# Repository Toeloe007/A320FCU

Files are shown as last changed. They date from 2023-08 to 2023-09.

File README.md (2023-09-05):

# A320FCU
Homebuilt FCU for the Fenix A320 (MSFS2020) 50-60€

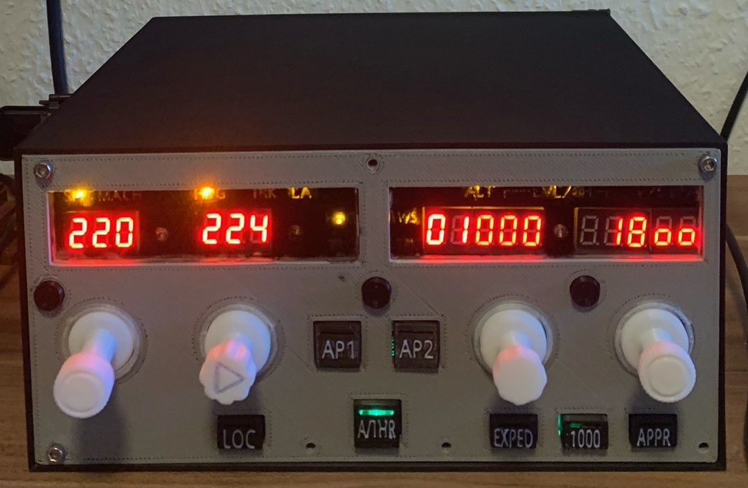
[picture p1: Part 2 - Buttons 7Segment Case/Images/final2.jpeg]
Preview


Since English is not my native language, I apologize in advance for any spelling and grammatical errors.

I would like to share my self-built FCU with you. It is relatively similar to the real FCU and includes all functions. It is also very interesting in price, you just have to invest time in the project.

The project is divided into 2 parts. 
- [Part 1 - knobs with push pull function and backlighting](./Part%201%20-%20Rotary%20Buttons/)
    - Inspired by [Mantoga](https://www.printables.com/de/model/504680-airbus-a320-fcu-push-pull-mechanism), who provided the print files of the push-pull mechanism.
- [Part 2 - The 7 segment displays, all LEDS and the box](./Part%202%20-%20Buttons%207Segment%20Case/)

## Basic Requirements
- 3D Printer with Slicer Software
    - Color Transparent
    - Color White
    - Color Grey
    - Color black
- Some knowledge about electricity
- Arduino Mega
- [Project Fenix Quartz](https://github.com/Fragtality/FenixQuartz)
- Mobiflight

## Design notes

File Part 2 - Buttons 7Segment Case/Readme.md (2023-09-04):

# Part 2 - 7Segment Displays, Buttons and LEDs
This part covers the assembly of the 7Segment Display, the Buttons and the LED

## Parts needed
- 16x [LED yellow](https://de.aliexpress.com/item/32757762886.html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)
- 7x [LED green](https://de.aliexpress.com/item/32757762886.html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)
- 16 [8x8 Non-Self-Locking Button](https://de.aliexpress.com/item/4001159367703.html?spm=a2g0o.cart.0.0.5fbb4ae4lgbDyt&mp=1&gatewayAdapt=glo2deu)
- 2x [10uF elektrolyt capacitor](https://de.aliexpress.com/item/32951751425.html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)
- 2x [100nF cermaic capacitor](https://de.aliexpress.com/item/1005001356274653.html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)
- 4x [7 segment 3 Bit 0.36 common cathode](https://de.aliexpress.com/item/1005005667523190.html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)
- 2x [7 segment 2 Bit 0.36 common cathode](https://de.aliexpress.com/item/1005005667523190.html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)
- 2x [Max 7219](https://de.aliexpress.com/item/1005004266394173.html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)
- 2x [DIP24](https://de.aliexpress.com/item/1005005432295225.html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)
- Some [PCD Boards](https://de.aliexpress.com/item/1005004818919331.html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)

## Preview
[Finished assembly](./Images/)

## Electronic Shematic
TODO

# 3D Printing
## Front
Print the front with 50% infill

## Buttons
All Buttons can be printed with 10% infill.

## Electrical assembly
Take a look to the [Datasheets](./Datasheets/) and doublecheck if you have the same 7Segment Display as the datasheet is. Otherwise get the correct datasheet. 

Wiring is easy but takes a lot of time.
One Max7219 can handle 8Digits. You have 16 Digits, so you need 2 Max7219. 

I have connected Speed, Heading and the first 2 digits of the Alt display to the first 7219. The remaining 3 digits of the Alt display and all digits of the VS display are connected to the second 7219.

The segments of the displays that belong on a Max7219 must all be connected together. The segment connections are each connected individually to the 7219. See the data sheets. Additionally the 7219 needs 5V at the V+ input. In parallel to the power supply 2 capacitors must be connected in parallel. A 10uF electrolytic capacitor and a 100nF cermaic capacitor. The other side of the capacitor belongs to GND. Furthermore the 7219 needs at the ISET input a 41k Ohm resistor with a 5V power supply.

Wiring the rest is pretty simple. Each button needs GND and is connected to the Arduino at the switch wire. Each LED needs a series resistor. I recommend to try each light color with different resistors to get the desired brightness. Please note that 20mA per output should not be exceeded.

Pin Arduino | Description 
38	        | AP1 Btn  
39	        | Ap1 LED  
40	        | AP2 Btn  
41	        | AP2 LED  
42	        | LOC BTN  
43	        | LOC LED  
44	        | ATHR BTN  
45	        | ATHR LED  
46	        | EXPED BTN  
47	        | EXPED LED  
48	        | 1000 Btn  
49	        | 1000 LED  
50	        | APP BTN  
51	        | APP LED  
52	        | SPD Mach Btn  
53	        | HDG TRK Btn  
2	        | MET ALT Btn  
3	        | SPD LED  
4	        | MACH LED  
5	        | HDG LED  
6	        | TRK LED  
7	        | VS LED  
8	        | FPA LED  
9	        | SPD Managed LED  
10	        | HDG Managed LED  
11	        | Alt Managed LED  

## Assembly
In the 3D files directory there are different Pins to glue the components together.

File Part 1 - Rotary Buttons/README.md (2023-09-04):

# Part 1 - Rotary Buttons with Push Pull Function
This part covers the assembly of the Rotary Button with Push Pull function.

## Parts needed
- 16 [8x8 Non-Self-Locking Button with Black Cap](https://de.aliexpress.com/item/4001159367703.html?spm=a2g0o.cart.0.0.5fbb4ae4lgbDyt&mp=1&gatewayAdapt=glo2deu)
- Rubber mat 2mm
- 6mm Brass Shaft approx 4x125mm
- 4x 20x2mm Steel Pin
- 4x [Rotary Encoder](https://de.aliexpress.com/item/1005002358274622.html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)
- 12x [Warm White LED 3x3mm Flat Top](https://de.aliexpress.com/item/32757762886.html?spm=a2g0o.cart.0.0.230b4ae42b9wfW&mp=1&gatewayAdapt=glo2deu)
- Wiring Material
- Rapid glue
- [Power Module](https://de.aliexpress.com/item/4000532944497.html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) for Backlight and 7 Segment display 5V-5W
- [Power Plug with Switch](https://de.aliexpress.com/item/1005002288319626.html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) for Power Module
- 12x 220 Ohm resistor for LED lighting

## Preview
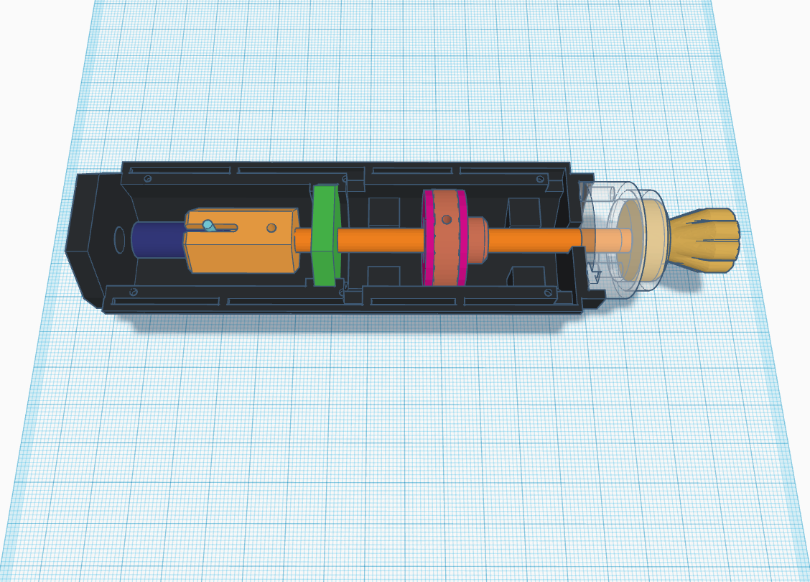
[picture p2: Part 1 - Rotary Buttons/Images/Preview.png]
Preview

[Finished assembly](./Images/)

## Electronic Shematic
[Backlight Shematic](./Electronics/Backlight_shematic.png)  
[Example Shematic](./Electronics/Example-shematic.png)

## 3D Printing
Print everything with 10% infill except the transparent part. Print the transparent part with 0% infill.

## Assembly
It is recommended to assemble 1 knob first as a test. And then learn from your mistakes.
1. print all 3D parts
2. glue the two parts of the button together
3. take a 6mm drill and drill the Light Pipe Support and the Centre Support (photo green) a little bit bigger. The brass rod must go through without friction. 
4. Glue the transparent part on the housing. ATTENTION: Put a LED in the lower cutout before, otherwise you won't be able to reach it.
5. install the encoder
6. glue the steel pin into the encoder pin. (photo cyan and dark blue)
7. glue the punched out rubber mat (photo pink) on the push pull disc.
8. put everything together carefully and check if the brass rod has the right length. If not, shorten the rod.
9. Remove everything except the encoder pin. 
10. put super glue in the hole of the encoder slide and put the encoder slide on the encoder pin
11. insert Centre Support
12. insert brass rod and don't forget the push pull disc!!!
13. glue brass rod and Encoder Slide together
14. wire the push button and glue it. Make sure that the Push Pull Disc is still free to move after gluing in the push buttons. Approx. 1mm distance
15. Push the brass rod almost all the way to the back. Approx. 1mm distance
16. push the push pull disc backwards. Operate the push mechanism and glue the push pull disc in the same way. 
17. After the glue has dried, operate the push mechanism again and glue the knob flush with the light pipe in this state.

If everything is done correctly, you can turn the knob and feel the steps of the encoder. In addition, you can press the push-pull mechanism and it will return to its original position by itself.

## Electrical assembly
All parts are connected to GND. This means that the middle pin of the encoder has to be connected to GND and the pushbuttons also all need GND. The push buttons have to be connected in parallel. So the push buttons for push together and the push buttons for pull together.

Pin Arduino | Description  
22	        | Altitude left  
23	        | Altitude right  
24	        | Push Altitude  
25	        | Pull Altitude  
26	        | Speed left  
27	        | Speed right  
28	        | Push Speed  
29	        | Pull Speed  
30	        | VS left  
31	        | VS right  
32	        | Push VS  
33	        | Pull VS  
34	        | HDG left  
35	        | HDG right  
36	        | Push HDG  
37	        | Pull HDG  

### Backlight
Since I don't want to load my USB ports unnecessarily, I decided to power the backlight via an external power supply.
The GND pin of the power module has to be connected to the GND pin of the Arduino.

The cathodes (-) of the LEDs can all be connected together and then connected to GND.
Each LED needs a 220 Ohm resistor at the anode (+). Connect all resistors together on one side and put them on the 5V of the power module.

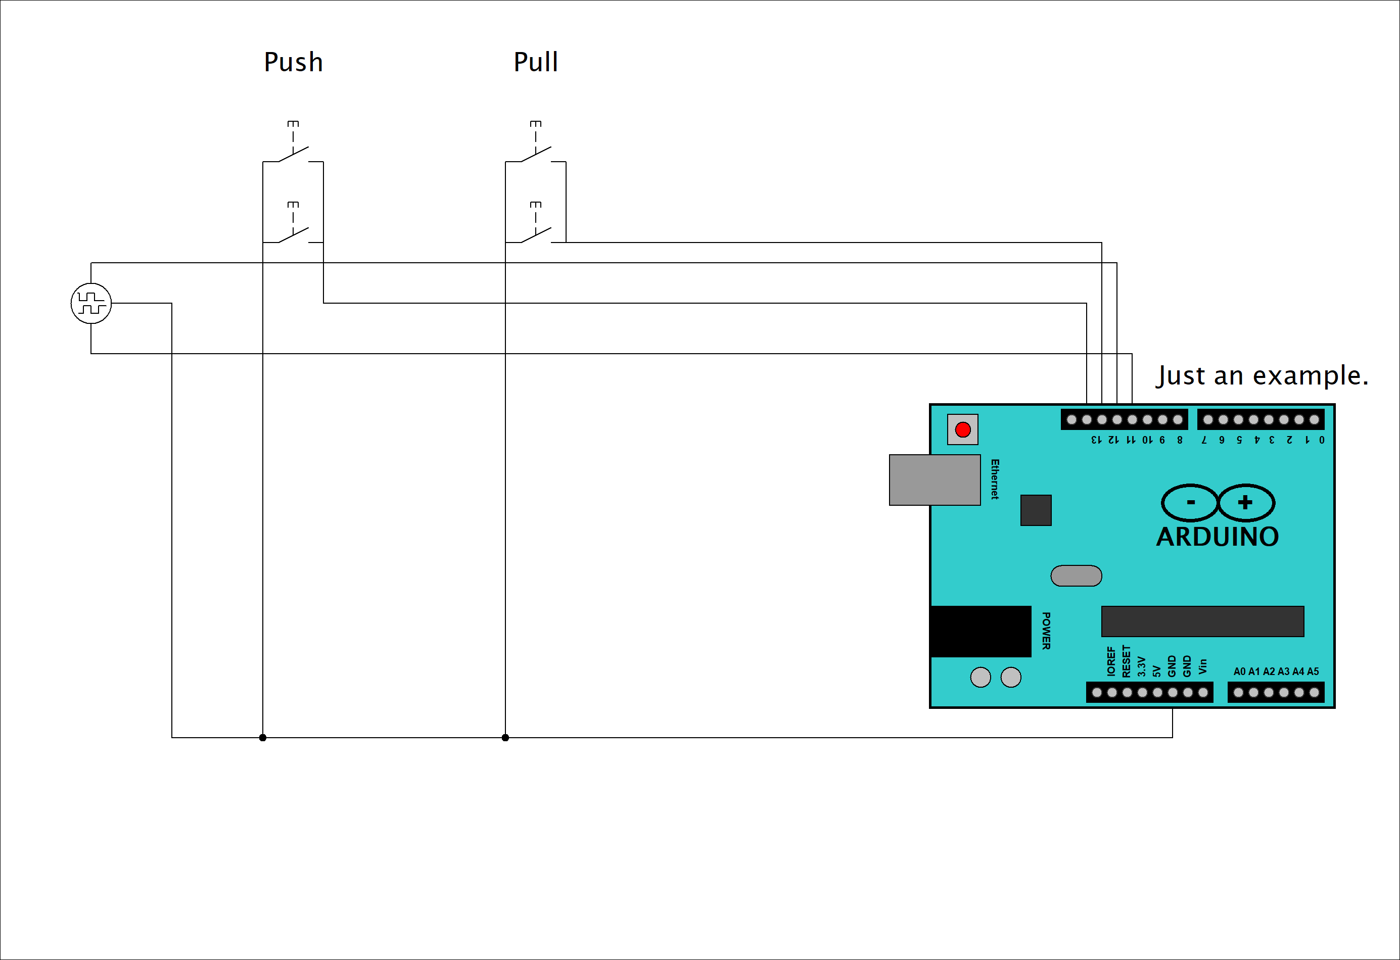
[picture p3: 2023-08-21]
Part 1 - Rotary Buttons/Electronics/Example-shematic.png

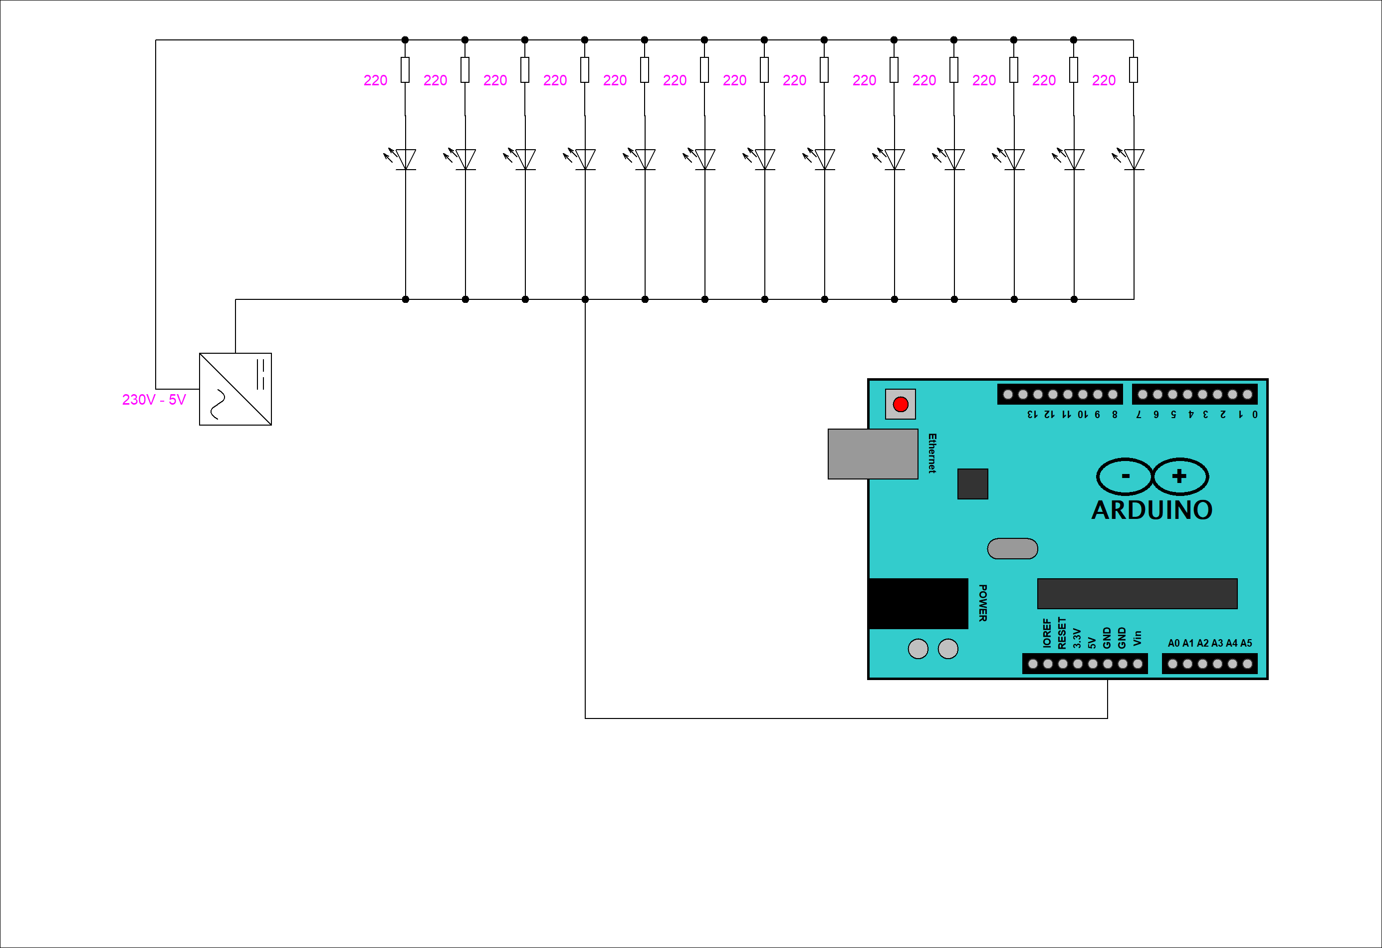
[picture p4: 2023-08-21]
Part 1 - Rotary Buttons/Electronics/Backlight_shematic.png

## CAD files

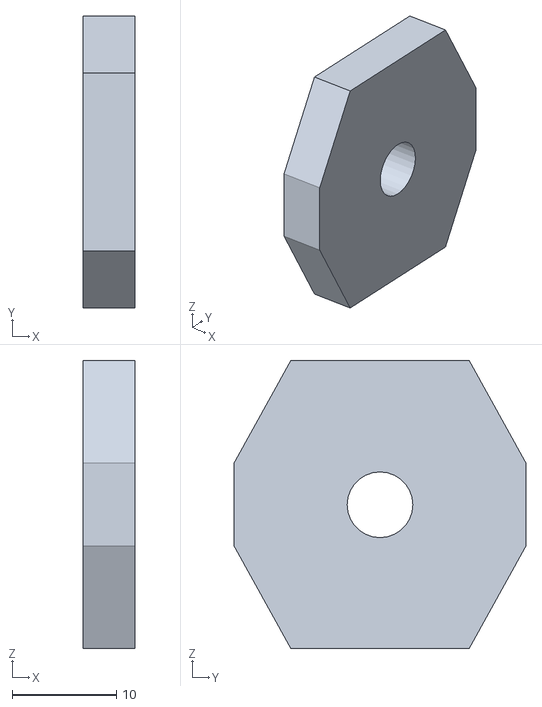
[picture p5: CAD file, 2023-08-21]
Part 1 - Rotary Buttons/3D Files/4x black Centre Support.stl
5.00 x 28.0 x 27.7

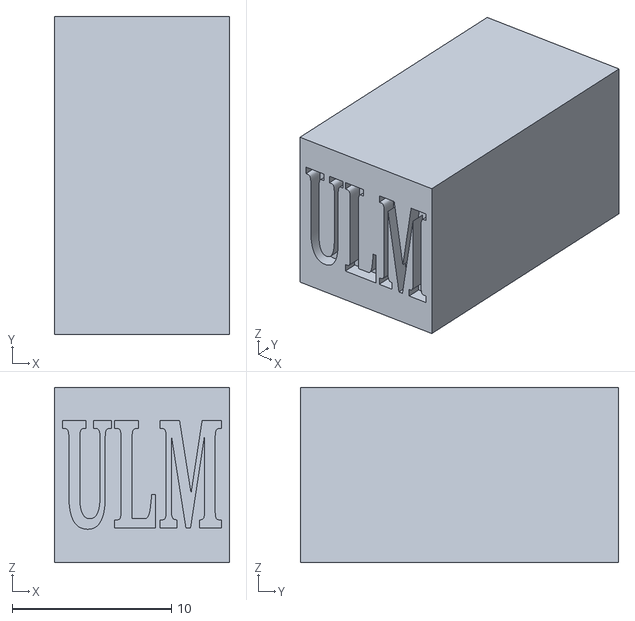
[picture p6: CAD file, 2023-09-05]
Part 2 - Buttons 7Segment Case/3D Files/Box_ULM.stl
11.0 x 20.0 x 11.0

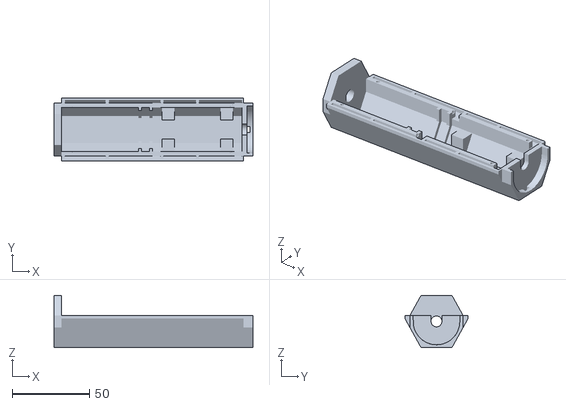
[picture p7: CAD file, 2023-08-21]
Part 1 - Rotary Buttons/3D Files/4x black Chassis.stl
129.0 x 41.0 x 34.0

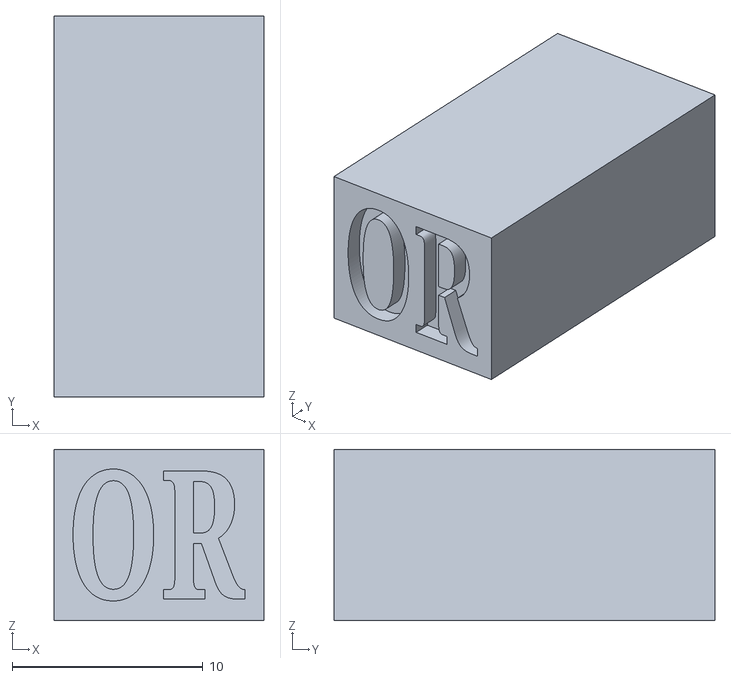
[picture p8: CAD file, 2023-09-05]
Part 2 - Buttons 7Segment Case/3D Files/Box_OR.stl
11.0 x 20.0 x 9.00

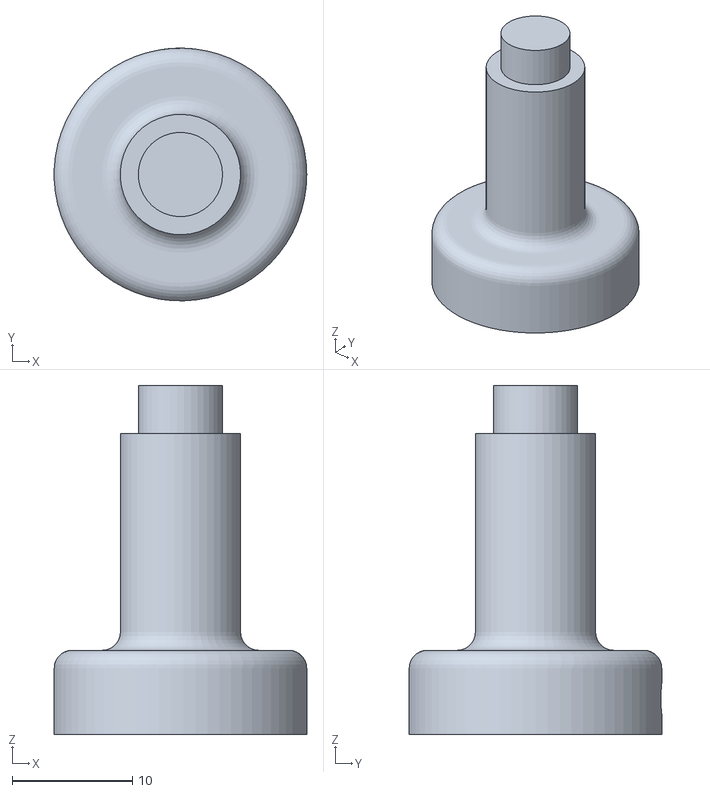
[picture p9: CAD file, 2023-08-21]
Part 1 - Rotary Buttons/3D Files/1x white Speed Knob Base.stl
21.0 x 21.0 x 29.0

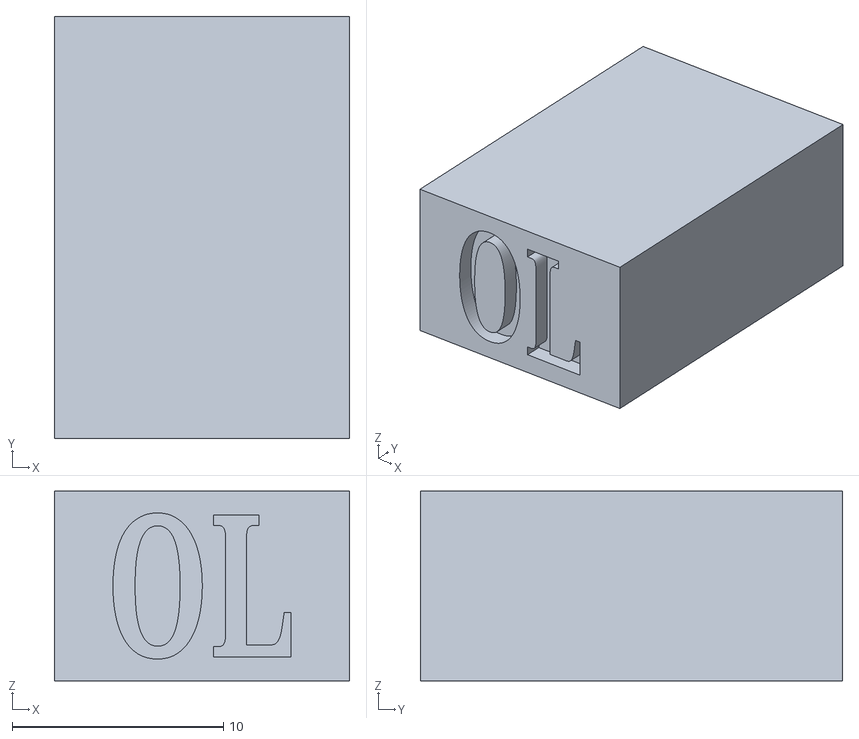
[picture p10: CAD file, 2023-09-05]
Part 2 - Buttons 7Segment Case/3D Files/Box_OL.stl
14.0 x 20.0 x 9.00

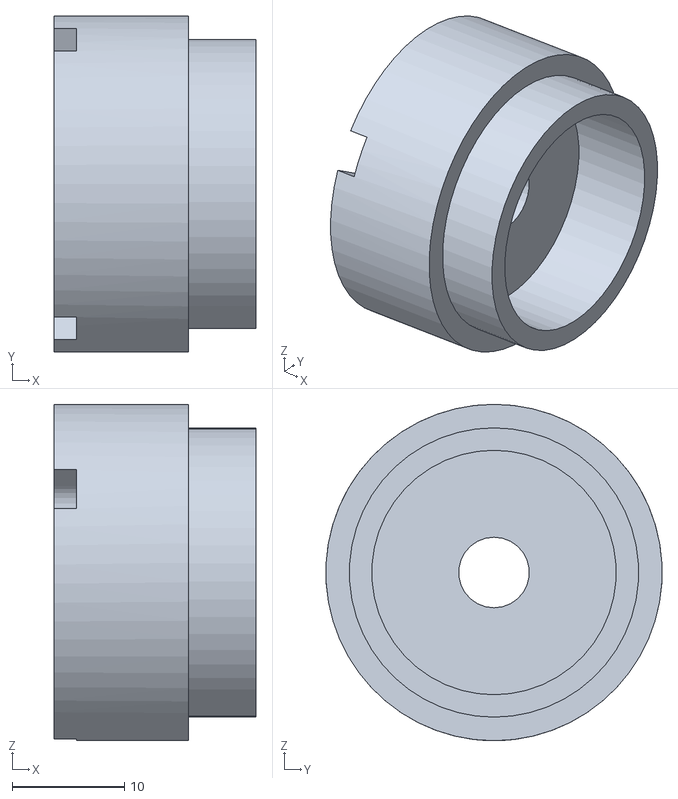
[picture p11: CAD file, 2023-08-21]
Part 1 - Rotary Buttons/3D Files/4x trans 0infill Light Pipe Front Support.stl
18.0 x 30.0 x 30.0

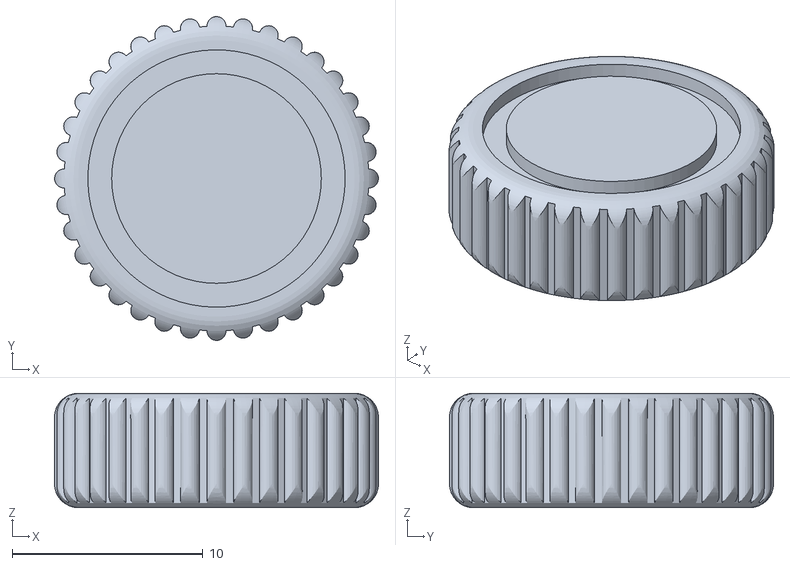
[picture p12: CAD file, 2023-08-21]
Part 1 - Rotary Buttons/3D Files/1x white VS Knob.stl
17.0 x 17.0 x 6.00

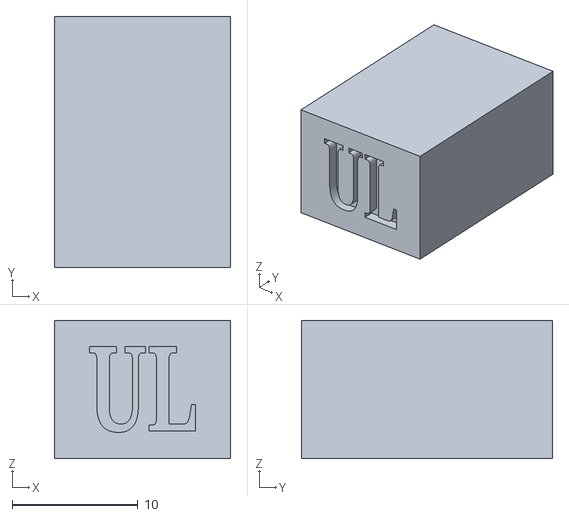
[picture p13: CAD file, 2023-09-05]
Part 2 - Buttons 7Segment Case/3D Files/Box_UL.stl
14.0 x 20.0 x 11.0

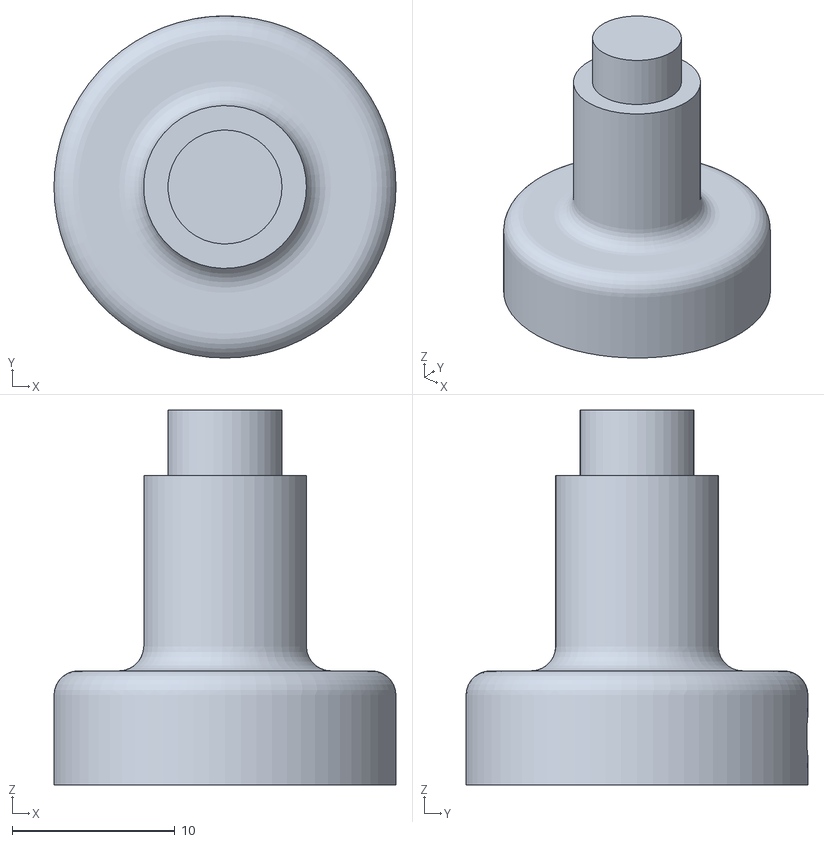
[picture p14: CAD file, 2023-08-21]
Part 1 - Rotary Buttons/3D Files/2x white VS Knob Base.stl
21.0 x 21.0 x 23.0

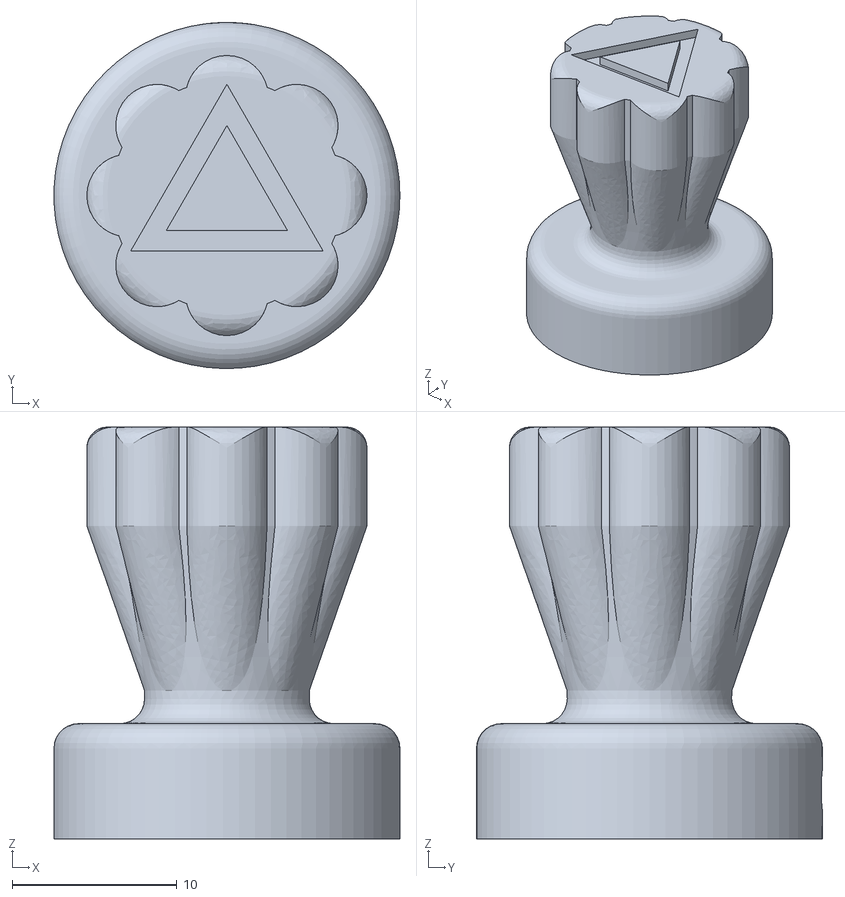
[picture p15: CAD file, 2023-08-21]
Part 1 - Rotary Buttons/3D Files/1x white HDG Knob.stl
21.0 x 21.0 x 25.0

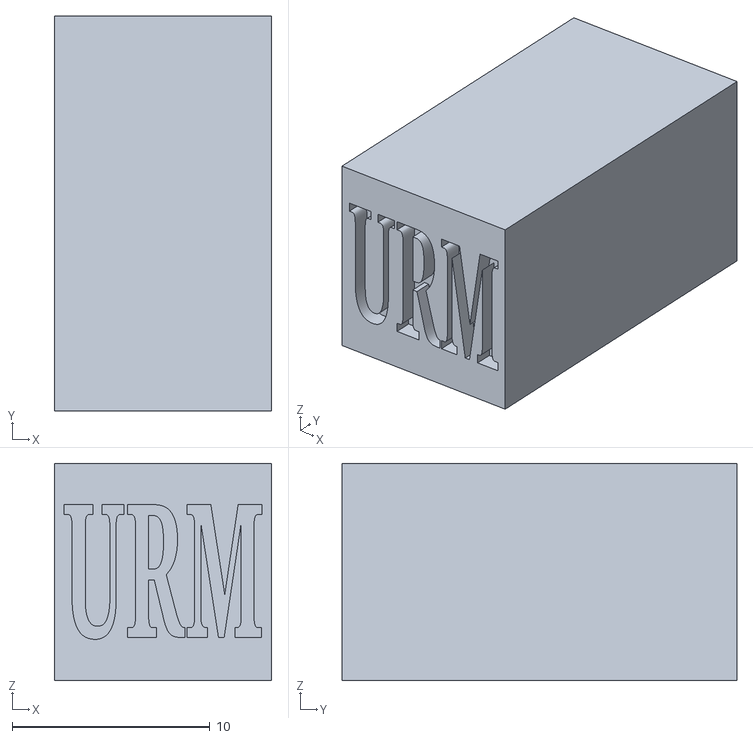
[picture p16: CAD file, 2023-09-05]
Part 2 - Buttons 7Segment Case/3D Files/Box_URM.stl
11.0 x 20.0 x 11.0

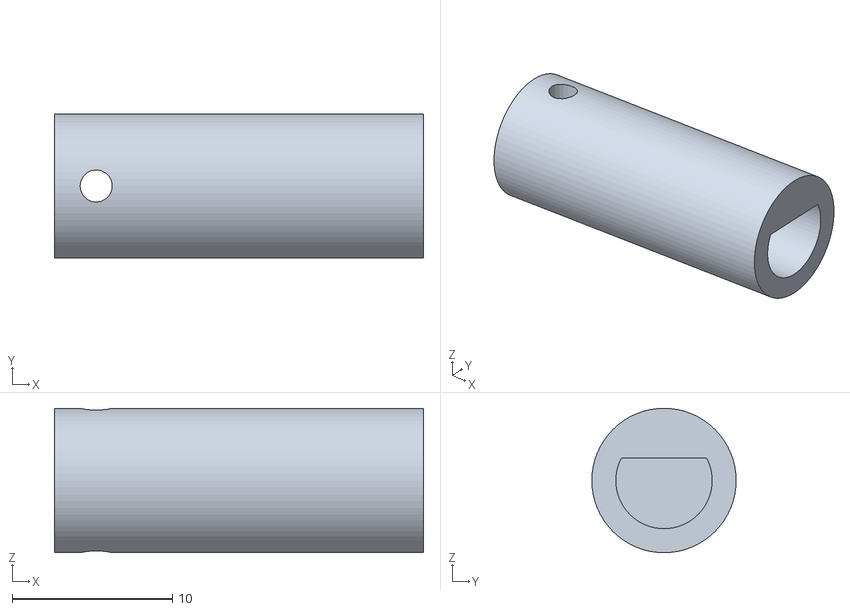
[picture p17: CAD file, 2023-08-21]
Part 1 - Rotary Buttons/3D Files/4x Encoder Pin.stl
23.0 x 9.00 x 9.00

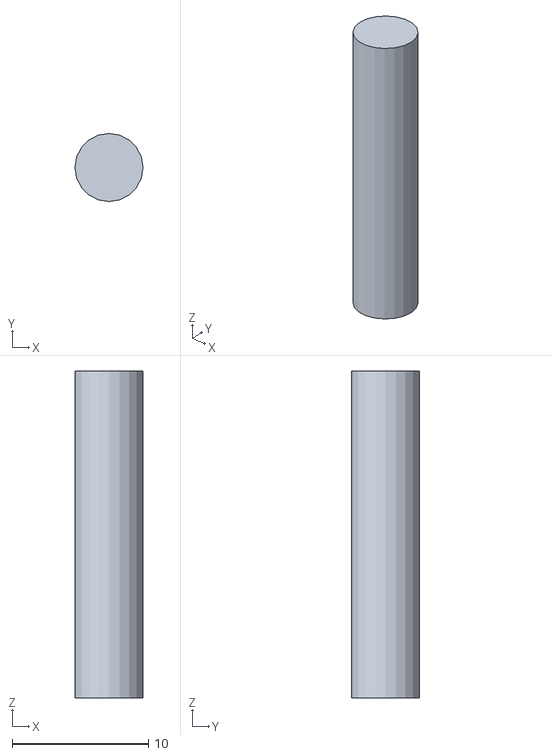
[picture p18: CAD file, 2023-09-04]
Part 2 - Buttons 7Segment Case/3D Files/5x24Display Pin.stl
5.00 x 5.00 x 24.0

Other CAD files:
Part 2 - Buttons 7Segment Case/3D Files/Box_UR.stl
Part 2 - Buttons 7Segment Case/3D Files/Box_OM.stl
Part 1 - Rotary Buttons/3D Files/1x white Speed Knob.stl
Part 2 - Buttons 7Segment Case/3D Files/3x11Display Pin.stl
Part 1 - Rotary Buttons/3D Files/1x white ALT Knob .stl
Part 1 - Rotary Buttons/3D Files/4x black Push Pull Disc.stl
Part 1 - Rotary Buttons/3D Files/4x black Encoder Slide.stl
Part 2 - Buttons 7Segment Case/3D Files/1000_Btn.stl
Part 2 - Buttons 7Segment Case/3D Files/1000_Text.stl
Part 2 - Buttons 7Segment Case/3D Files/5x11Display Pin.stl
Part 2 - Buttons 7Segment Case/3D Files/5x16Display Pin.stl
Part 2 - Buttons 7Segment Case/3D Files/AP1_Btn.stl
Part 2 - Buttons 7Segment Case/3D Files/AP1_Btn_smaller.stl
Part 2 - Buttons 7Segment Case/3D Files/AP1_Text.stl
Part 2 - Buttons 7Segment Case/3D Files/AP1_Text_smaller.stl
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

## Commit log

2023-08-21 First Commit Part 1
    [1x white ALT Knob .stl, 1x white HDG Knob.stl, 1x white Speed Knob Base.stl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]
2023-08-30 Part 2
    [1000_Btn.stl, 1000_Text.stl, 4x trans 0infill Light Pipe Front Support.stl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]
2023-09-04 Add some more files
    Added multiple 3D Files that helps to glue all the part together. Made some changes in Mobiflight
    [3x11Display Pin.stl, 5x11Display Pin.stl, 5x16Display Pin.stl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]
2023-09-05 added some final files
    [Box_OL.stl, Box_OM.stl, Box_OR.stl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]
